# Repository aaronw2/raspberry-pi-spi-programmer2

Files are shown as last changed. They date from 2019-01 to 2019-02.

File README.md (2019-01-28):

SOIC-8 and SOIC-16 SPI Flash Programming Hat for Raspberry PI

This hat allows the Raspberry PI to program both SOIC-8 and SOIC-16 SPI
NOR devices at 1.8 and 3.3 volts.  All features of this programmer can
be controlled via software.

While the current version of the board has switches and jumpers present,
a future version of this board will no longer require them since everything
can be controlled by GPIO pins.

SW1: This switch will enable and disable the programmer.  When disabled,
the power and signals to the sockets will be disabled and SPI NOR chips
may be safely installed or removed.  Software is able to read this switch
and a future software version will be able to override the switch.

SW2: This sets the voltage to use for powering and programming the SPI NOR
chips.  Software can read the position of this switch and a future version
of the software will be able to both read and override the switch setting.

JP1: This jumper should be installed if the board this hat is plugged into
does not support SPI chip select 1.  For example, the Rock64Pro board does
not provide CS1.  Software can read whether this jumper is installed or not
and can override the jumper.  A future version of the software will not
need the jumper since it will detect what type of board it is running on.

The SOIC-16 socket will only run in single lane mode.  Lanes 1, 2 and 3
are not supported by the Raspberry PI.

LEDs:
This board has 6 LEDs.

Power: D6: The white LED in the upper left will be lit when 5V is present.
Enabled: D1: This red LED will be lit when power is enabled to the sockets.
3.3V: D2: This LED will be lit when the board is configured for 3.3V
1.8V: D3: This LED will be lit when the board is configured for 1.8V
CS0: D4: This LED will light when there is activity with SPI CS0.
CS1: D5: This LED will light when there is activity with SPI CS1.

GPIOs used:
BMC17: Pin 13: This pin can be input or output.  If high, then 3.3 volts is
               selected, otherwise 1.8v is selected.  If not driven, then
               switch SW2 will control the signal.
BCM22: Pin 15: This pin is used to disable power and tri-state the outputs
               to the sockets.  This pin can be read, in which case SW1 will
               control the signal, or it may be driven to override the switch.
BCM5: Pin 29:  This pin is used to control whether CS1 is driven by CS0 or not.
               This pin can be read in which case the state can be controlled
               by JP1, or it can be driven to override the jumper.  This is
               needed if the board the hat is plugged in to does not support
               SPI CS1 such as the Rock64Pro board.

SPI pins:
BCM10: Pin 19: SPI MOSI signal
BCM9: Pin 21: SPI MISO signal
BCM11: Pin 23: SPI SCLK
BCM8: Pin 24: SPI CS0
BCM7: Pin 26: SPI CS1

I2C Pins:
BMCM0: Pin 27: EEPROM I2C SDA
BMC1: Pin 28: EEPROM I2C SCL

Power: This board draws power from 5V and 3.3V for internal logic.  The
       sockets power and socket I/O is controlled by a built-in regulator
       that uses the 5V supply to generate either 1.8 or 3.3V.

All parts can be found at https://digikey.com

=========== Using ==============

Do not install SPI NOR flash devices in both sockets at the same time.  A
future version of this board may support devices in both sockets.

1. Make sure that the board is in the disabled state
2. Select the proper voltage for the devices
3. Install a SOIC-8 and/or SOIC-16 SPI NOR device into the appropriate socket.
   Note: If not using a Raspberry PI do not install devices in both
         sockets.
4. Run the software to program the device(s)
5. Wait until programming is finished and make sure the enabled LED is not
   lit.  Set the switch to the disabled position.
6. Remove the SPI device

Software: TBD
Todo: Get the board back and assemble and test it then work on software.

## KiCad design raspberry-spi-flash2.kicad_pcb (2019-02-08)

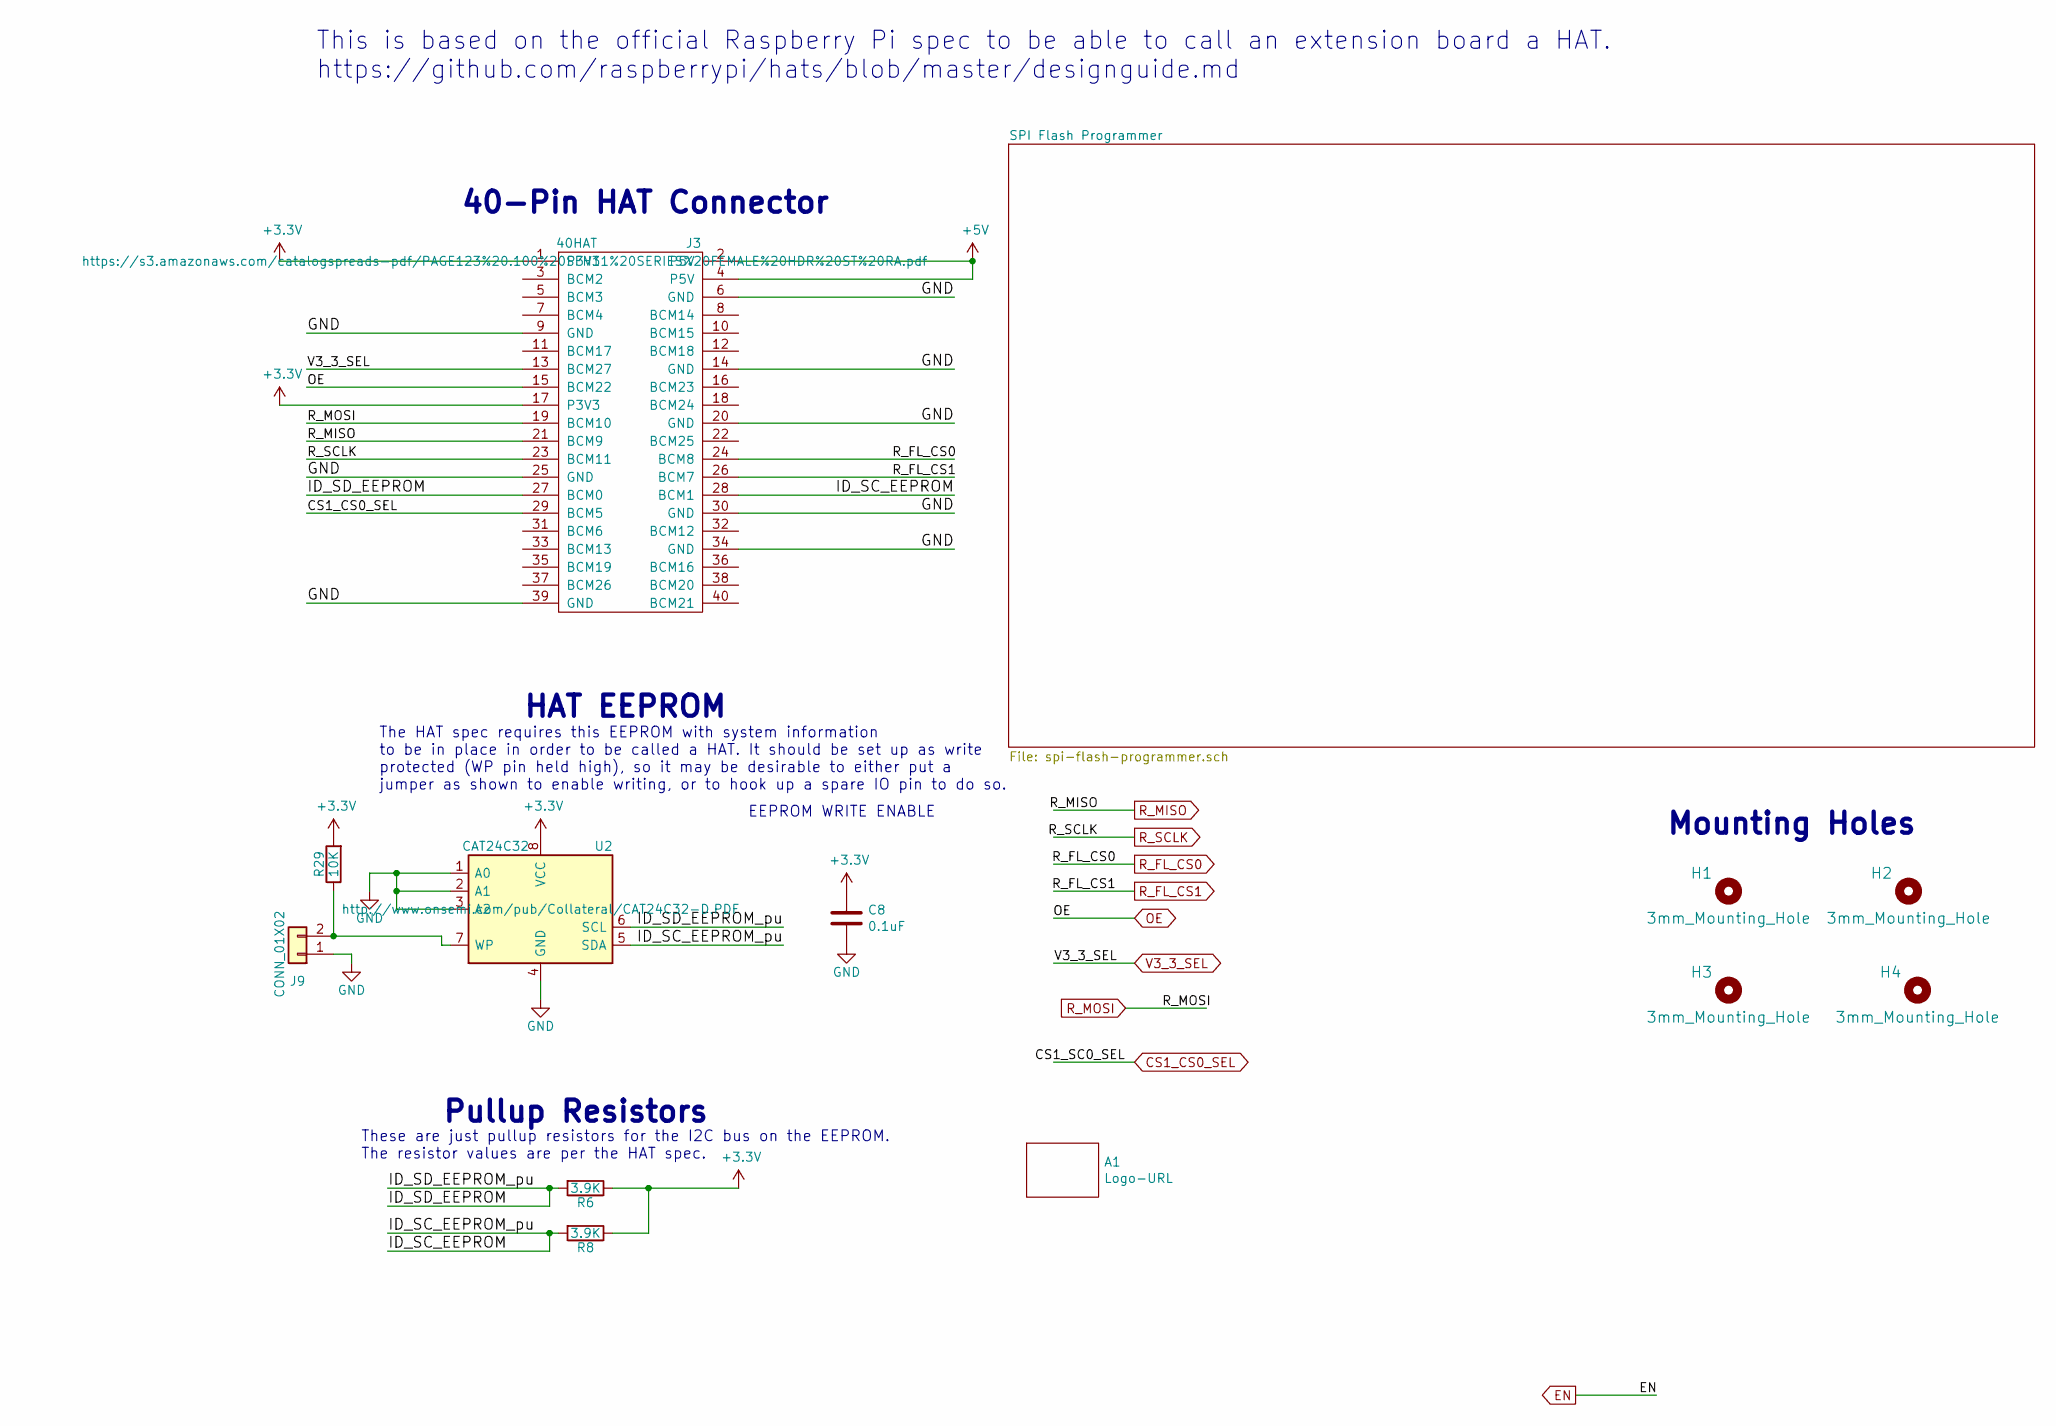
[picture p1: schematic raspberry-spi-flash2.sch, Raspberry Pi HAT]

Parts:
A1: Logo-URL; LOGO-raspberry-pi-spi-programmer2
C8: 0.1uF; C_0603_1608Metric
H1, H2, H3, H4: 3mm_Mounting_Hole; NPTH_3mm_ID
J3: 40HAT; PinSocket_2x20_P2.54mm_Vertical; MPN SFH11-PBPC-D20-ST-BK
J9: CONN_01X02; PinHeader_1x02_P2.54mm_Vertical
R6: 3.9K; R_0603_1608Metric; MPN RC0603FR-073K9L
R8: 3.9K; R_0603_1608Metric
R29: 10K; R_0603_1608Metric
U2: CAT24C32; SOIC-8_3.9x4.9mm_P1.27mm; MPN CAT24C32WI-GT3

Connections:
+3V3: C8.1, J3.1 (P3V3), J3.17 (P3V3), R6.1, R8.1, R29.2, U2.8 (VCC); also elsewhere on the board
+5V: J3.2 (P5V), J3.4 (P5V); also elsewhere on the board
/ID_SC_EEPROM: J3.28 (BCM1), R8.2, U2.5 (SDA)
/ID_SD_EEPROM: J3.27 (BCM0), R6.2, U2.6 (SCL)
CS1_CS0_SEL: J3.29 (BCM5); also elsewhere on the board
GND: C8.2, J3.6 (GND), J3.9 (GND), J3.14 (GND), J3.20 (GND), J3.25 (GND), J3.30 (GND), J3.34 (GND), J3.39 (GND), J9.1, U2.1 (A0), U2.2 (A1), U2.3 (A2), U2.4 (GND); also elsewhere on the board
unnamed: J9.2, R29.1, U2.7 (WP)
OE: J3.15 (BCM22); also elsewhere on the board
R_FL_CS0: J3.24 (BCM8); also elsewhere on the board
R_FL_CS1: J3.26 (BCM7); also elsewhere on the board
R_MISO: J3.21 (BCM9); also elsewhere on the board
R_MOSI: J3.19 (BCM10); also elsewhere on the board
R_SCLK: J3.23 (BCM11); also elsewhere on the board
V3_3_SEL: J3.13 (BCM27); also elsewhere on the board

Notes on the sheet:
EEPROM WRITE ENABLE
Pullup Resistors
HAT EEPROM
Mounting Holes
40-Pin HAT Connector
The HAT spec requires this EEPROM with system information to be in place in order to be called a HAT. It should be set up as write protected (WP pin held high), so it may be desirable to either put a jumper as shown to enable writing, or to hook up a spare IO pin to do so.
These are just pullup resistors for the I2C bus on the EEPROM. The resistor values are per the HAT spec.
This is based on the official Raspberry Pi spec to be able to call an extension board a HAT. https://github.com/raspberrypi/hats/blob/master/designguide.md

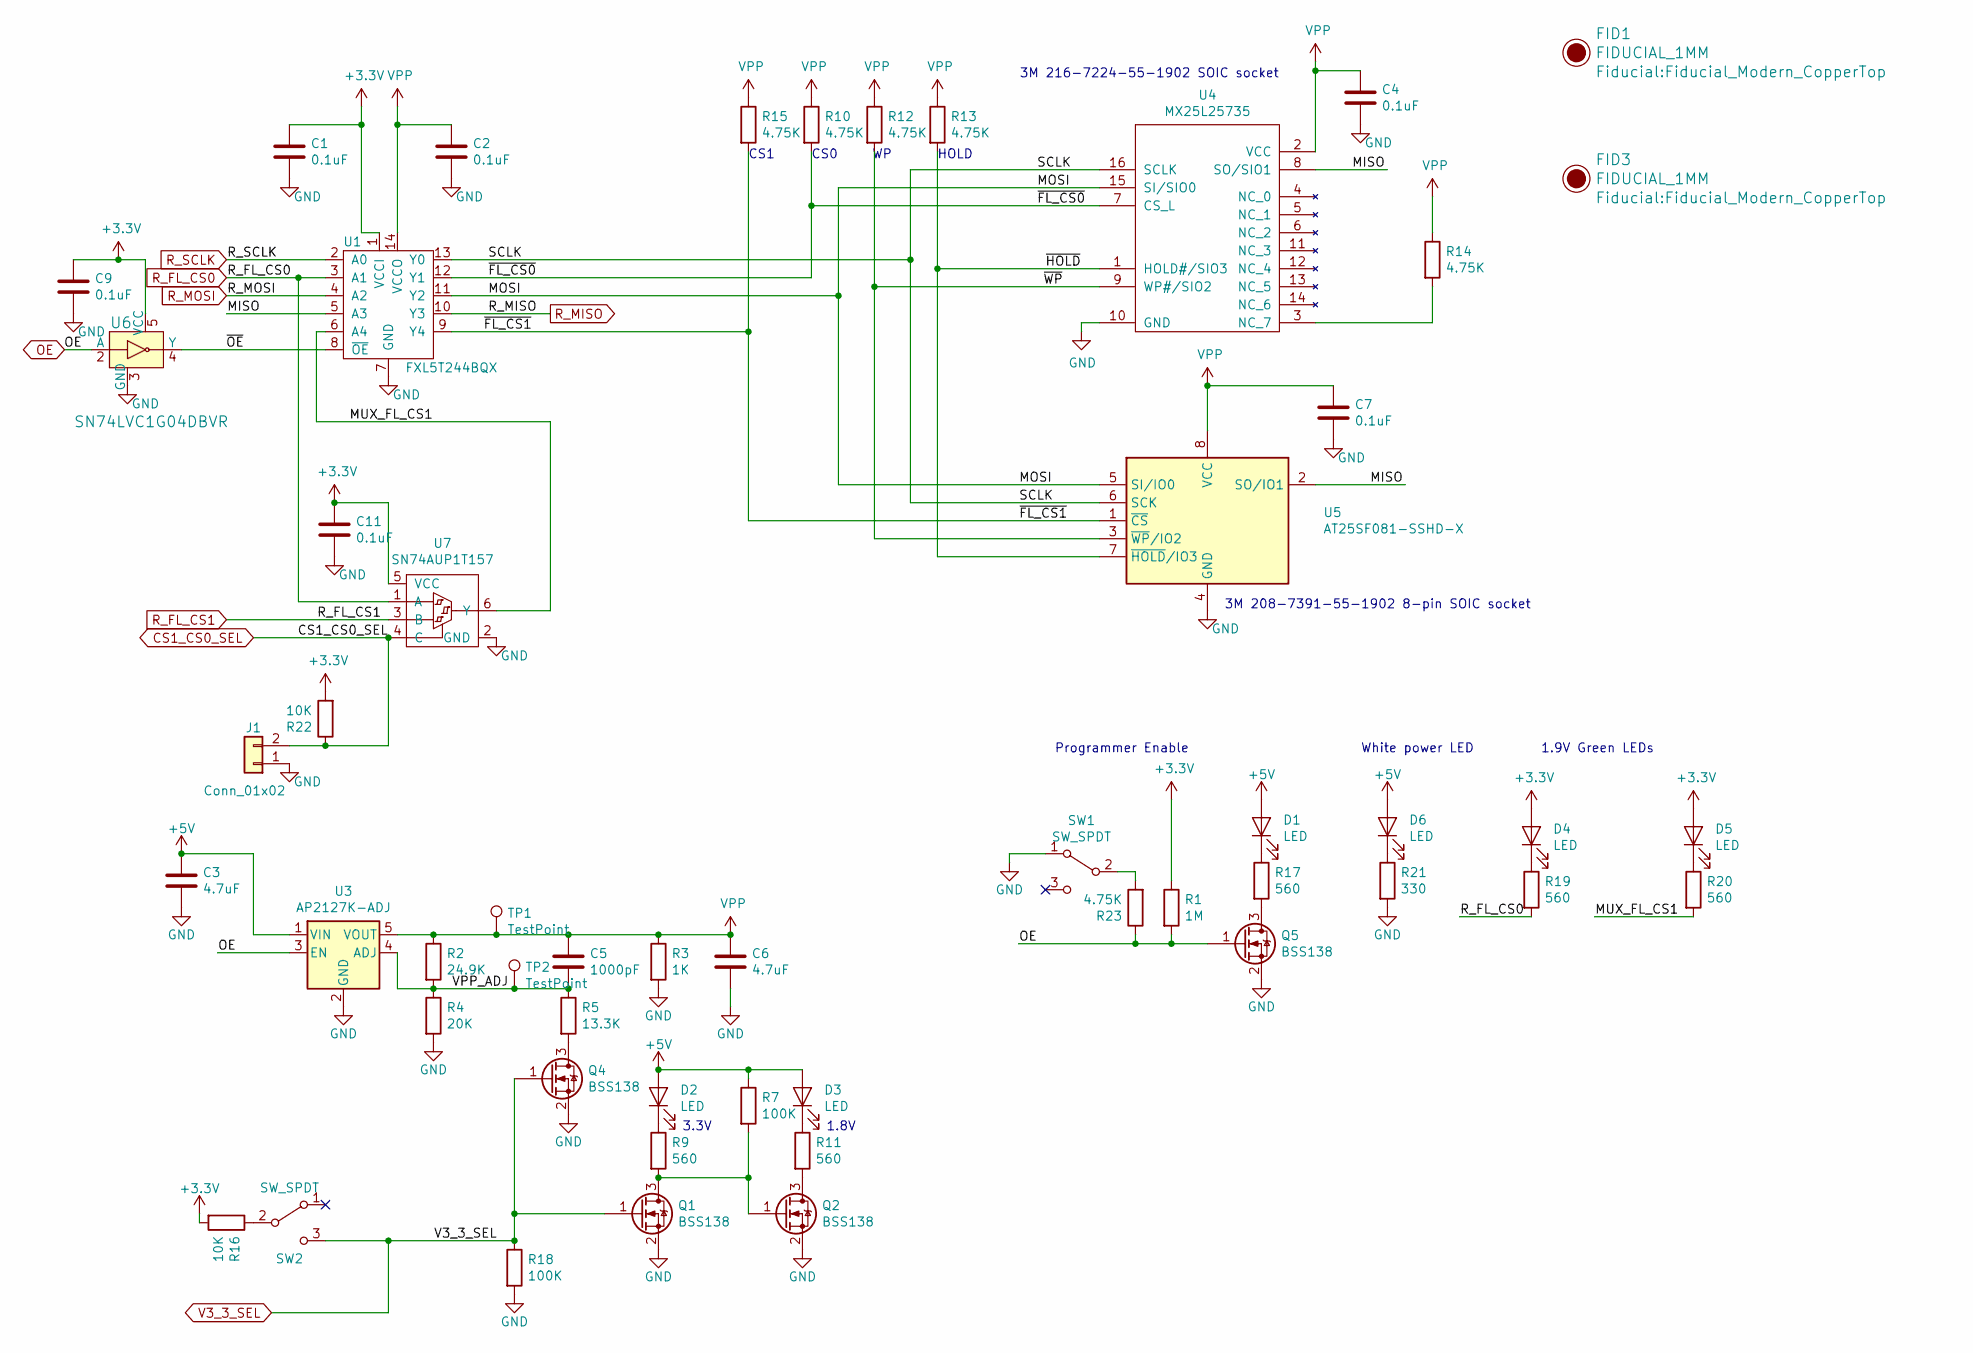
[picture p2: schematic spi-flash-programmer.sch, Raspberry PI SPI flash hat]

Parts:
C1, C2, C4, C7, C9, C11: 0.1uF; C_0603_1608Metric
C3, C6: 4.7uF; C_0603_1608Metric
C5: 1000pF; C_0603_1608Metric; MPN GRM188R61E475KE15D
D1, D2, D3: LED; LED_0603_1608Metric
D4, D5, D6: LED; LED_0603_1608Metric; MPN 5990060007F
FID1, FID3: FIDUCIAL_1MM; Fiducial_Modern_CopperTop
J1: Conn_01x02; PinHeader_1x02_P2.54mm_Vertical
Q1, Q2, Q4: BSS138; SOT-23
Q5: BSS138; SOT-23; MPN BSS138K
R1: 1M; R_0603_1608Metric
R2: 24.9K; R_0603_1608Metric; MPN RT0603DRE0724K3L
R3: 1K; R_0603_1608Metric
R4: 20K; R_0603_1608Metric; MPN RT0603FRE0720KL
R5: 13.3K; R_0603_1608Metric; MPN CRCW060313K3FKEA
R7, R18: 100K; R_0603_1608Metric
R9, R11, R17, R19, R20: 560; R_0603_1608Metric
R10, R12, R13, R14, R15, R23: 4.75K; R_0603_1608Metric
R16, R22: 10K; R_0603_1608Metric
R21: 330; R_0603_1608Metric
SW1, SW2: SW_SPDT; SW_STDP_CF-LD-1DC; MPN CF-LD-1DC-AW2W
TP1, TP2: TestPoint; TestPoint_THTPad_1.0x1.0mm_Drill0.5mm
U1: FXL5T244BQX; DQFN-14-1EP_2.5x3mm_EP2.2x1.7mm_Thermal
U3: AP2127K-ADJ; SOT-23-5
U4: MX25L25735; 216-7224-55-1902; MPN 216-7383-55-1902
U5: AT25SF081-SSHD-X; 208-7391-55-1902; MPN 208-7391-55-1902
U6: SN74LVC1G04DBVR; SOT-753; MPN SN74LVC1G04DBVR; Digi-Key_PN 296-11599-1-ND
U7: SN74AUP1T157; SOT-23-6; MPN SN74AUP1T157DCKR

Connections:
+3V3: C1.1, C9.1, C11.1, D4.2 (A), D5.2 (A), R1.1, R16.2, R22.2, U1.1 (VCCI), U6.5 (VCC), U7.5 (VCC); also elsewhere on the board
+5V: C3.1, D1.2 (A), D2.2 (A), D3.2 (A), D6.2 (A), R7.1, U3.1 (VIN); also elsewhere on the board
/SPI Flash Programmer/MISO: U1.5 (A3), U4.8 (SO/SIO1), U5.2 (SO/IO1)
/SPI Flash Programmer/MOSI: U1.11 (Y2), U4.15 (SI/SIO0), U5.5 (SI/IO0)
/SPI Flash Programmer/MUX_FL_CS1: R20.2, U1.6 (A4), U7.6 (Y)
/SPI Flash Programmer/SCLK: U1.13 (Y0), U4.16 (SCLK), U5.6 (SCK)
/SPI Flash Programmer/VPP_ADJ: C5.2, R2.2, R4.1, R5.1, TP2.1, U3.4 (ADJ)
/SPI Flash Programmer/~FL_CS0: R10.2, U1.12 (Y1), U4.7 (CS_L)
/SPI Flash Programmer/~FL_CS1: R15.2, U1.9 (Y4), U5.1 (~CS)
/SPI Flash Programmer/~HOLD: R13.2, U4.1 (HOLD#/SIO3), U5.7 (~HOLD~/IO3)
/SPI Flash Programmer/~OE: U1.8 (~OE), U6.4 (Y)
/SPI Flash Programmer/~WP: R12.2, U4.9 (WP#/SIO2), U5.3 (~WP~/IO2)
CS1_CS0_SEL: J1.2, R22.1, U7.4 (C); also elsewhere on the board
GND: C1.2, C2.2, C3.2, C4.2, C6.2, C7.2, C9.2, C11.2, J1.1, Q1.2 (S), Q2.2 (S), Q4.2 (S), Q5.2 (S), R3.2, R4.2, R18.2, R21.2, SW1.1 (A), U1.7 (GND), U3.2 (GND), U4.10 (GND), U5.4 (GND), U6.3 (GND), U7.2 (GND); also elsewhere on the board
unnamed: D1.1 (K), R17.1
unnamed: D2.1 (K), R9.1
unnamed: D3.1 (K), R11.1
unnamed: D4.1 (K), R19.1
unnamed: D5.1 (K), R20.1
unnamed: D6.1 (K), R21.1
unnamed: Q1.3 (D), Q2.1 (G), R7.2, R9.2
unnamed: Q2.3 (D), R11.2
unnamed: Q4.3 (D), R5.2
unnamed: Q5.3 (D), R17.2
unnamed: R14.2, U4.3 (NC_7)
unnamed: R16.1, SW2.2 (B)
unnamed: R23.2, SW1.2 (B)
OE: Q5.1 (G), R1.2, R23.1, U3.3 (EN), U6.2 (A); also elsewhere on the board
R_FL_CS0: R19.2, U1.3 (A1), U7.1 (A); also elsewhere on the board
R_FL_CS1: U7.3 (B); also elsewhere on the board
R_MISO: U1.10 (Y3); also elsewhere on the board
R_MOSI: U1.4 (A2); also elsewhere on the board
R_SCLK: U1.2 (A0); also elsewhere on the board
V3_3_SEL: Q1.1 (G), Q4.1 (G), R18.1, SW2.3 (C); also elsewhere on the board
VPP: C2.1, C4.1, C5.1, C6.1, C7.1, R2.1, R3.1, R10.1, R12.1, R13.1, R14.1, R15.1, TP1.1, U1.14 (VCCO), U3.5 (VOUT), U4.2 (VCC), U5.8 (VCC)

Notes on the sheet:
1.9V Green LEDs
White power LED
3M 216-7224-55-1902 SOIC socket
3M 208-7391-55-1902 8-pin SOIC socket
3.3V
1.8V
Programmer Enable
CS1
CS0
HOLD

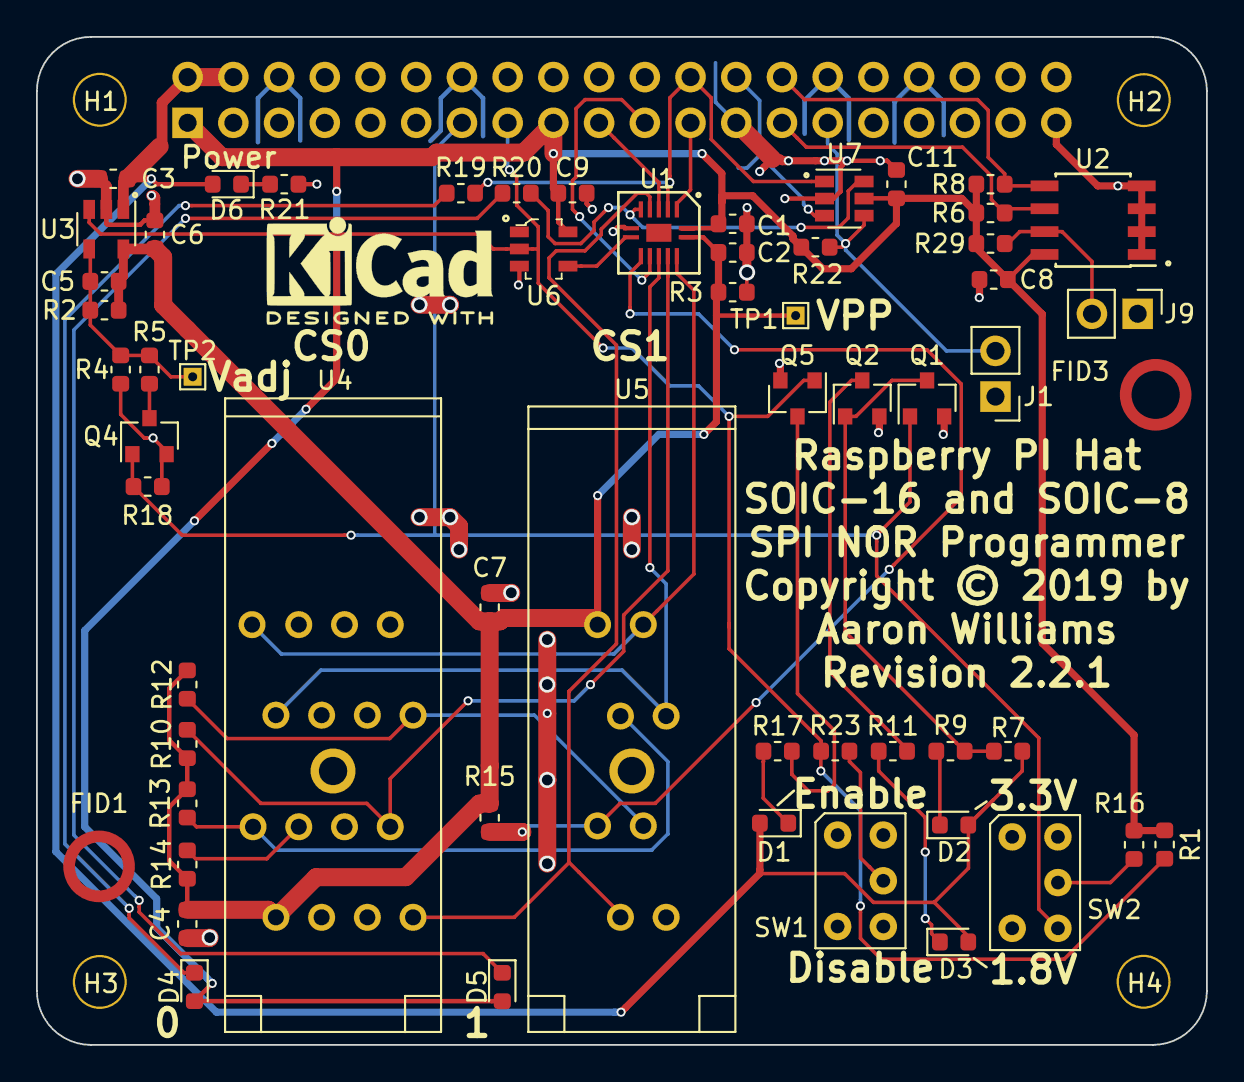
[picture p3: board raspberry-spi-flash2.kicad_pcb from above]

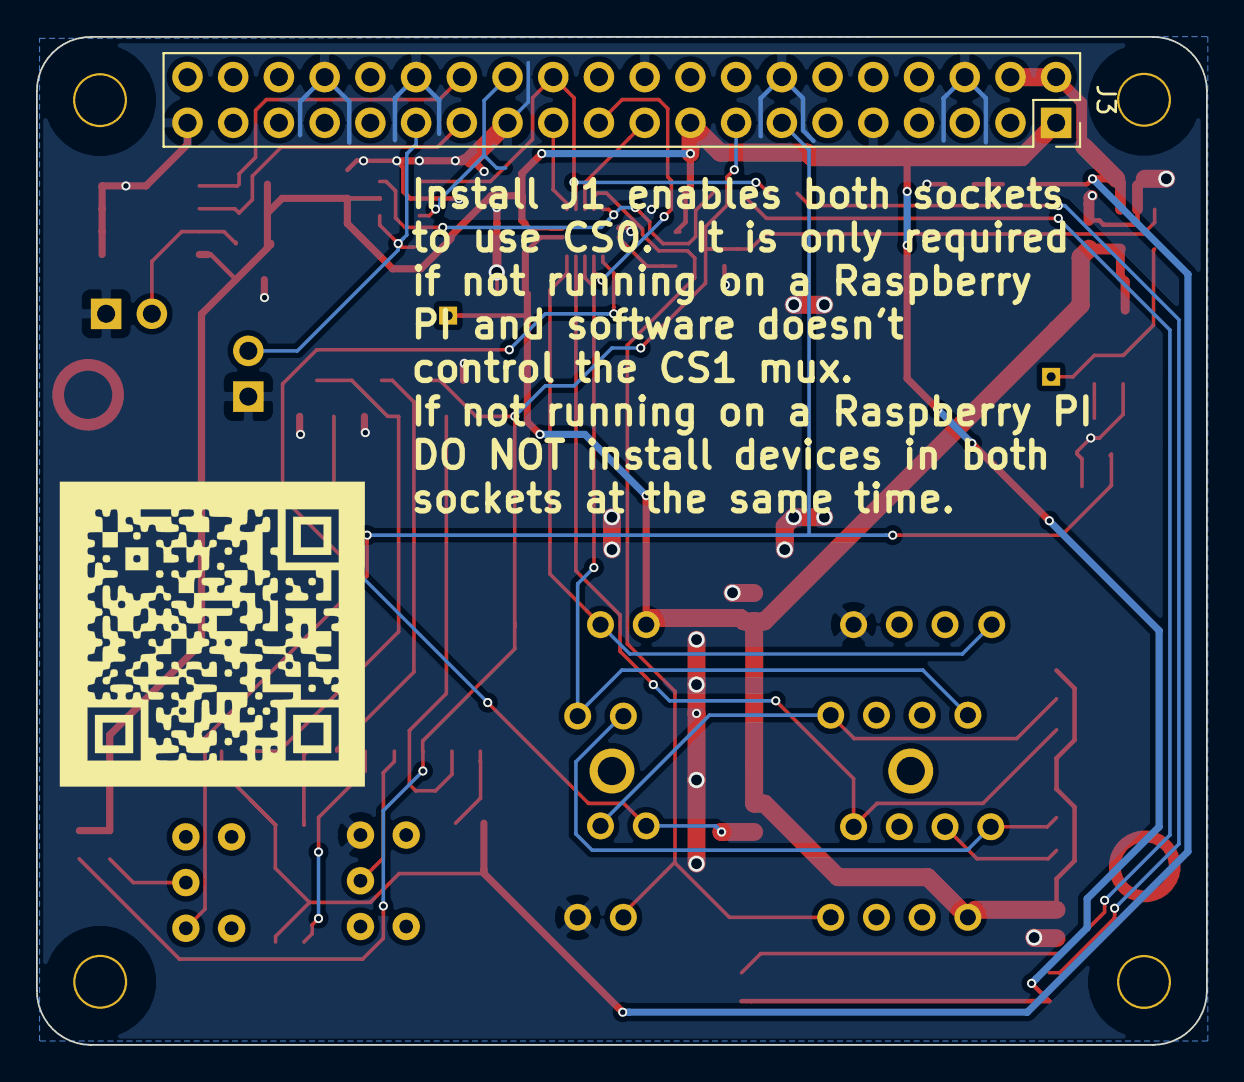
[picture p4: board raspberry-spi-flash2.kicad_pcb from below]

Board: 2 copper layers, 65.0 x 56.0 mm, 65 parts (2 on the bottom side), 38 nets.

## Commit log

2019-01-27 Added jumper to work with Rock64 board which lacks CS1.
    [raspberry-spi-flash2.kicad_pcb, spi-flash-programmer.sch]
2019-01-28 Fixes a number of issues
    This fixes a number of issues with the previous design.
    1. The OE GPIO pin was not hooked up.
    2. The level shifter has been changed to a 5 channel unidirectional
    level shifter.
    3. LEDs were moved down near the base.
    4. The switches were fixed based on measuring the contacts with different
    switch positions (not in the data sheet).
    5. Added support for some non-Raspberry PI boards.
    6. Changed resistors in power supply based on what is readily available.
    [raspberry-spi-flash2.kicad_pcb, raspberry-spi-flash2.sch, spi-flash-programmer.sch]
2019-02-08 Fixed solder mask setting and minor cleanups
    [raspberry-spi-flash2.kicad_pcb]

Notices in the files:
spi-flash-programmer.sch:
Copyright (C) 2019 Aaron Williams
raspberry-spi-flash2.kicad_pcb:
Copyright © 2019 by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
